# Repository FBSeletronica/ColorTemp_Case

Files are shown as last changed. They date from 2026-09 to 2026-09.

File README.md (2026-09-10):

# ColorTemp Case

3D-printed case for the [ColorTemp](https://github.com/MechatronixLab/ColorTemp/tree/master) project — a color-coded thermometer by Mechatronix Lab.

Modeled in OpenSCAD from the board's measurements (STEP), with a translucent lid that acts as a diffuser for the LED.

## Files

| File | Description |
|---|---|
| [ColorTemp_Case.scad](ColorTemp_Case.scad) | Parametric source (OpenSCAD) |
| [ColorTemp_Case_base.stl](ColorTemp_Case_base.stl) | Base, ready to slice |
| [ColorTemp_Case_lid.stl](ColorTemp_Case_lid.stl) | Lid/diffuser, ready to slice |

## Board fit

Base measurements (taken from the STEP file): 27.5 x 27.5 mm board, 1.6 mm thick.

- **USB-C** on the Y+ edge (connector rises 3.85 mm above the board)
- **Buttons** (SW1/SW2) on the X+ edge, with the actuator almost touching the wall
- The board snaps onto 4 locating pins and rests on standoffs
- A center hole in the bottom of the base allows for ventilation and lets you push the board out when disassembling

## Assembly

1. Snap the board onto the base's 4 locating pins.
2. Close the case by pressing the lid down until it locks onto the 4 snap blocks (1 per side) — no glue or screws needed.
3. To disassemble, push the board out from underneath through the base's center hole.

If the lid fit is too tight or too loose for your printer, adjust `snap_protrude`, `snap_depth`, or `fit_gap` near the top of the `.scad` file.

## Printing recommendations

- **0% infill** on both parts — with walls this thin, any infill would kill the lid's light diffusion and might even prevent it from closing properly.
- **Lid:** force **1 single perimeter/wall-loop** in your slicer (the default is usually 2+) to get a wall thin enough (~0.45–0.5 mm) to diffuse the LED's light. Tested with a 0.4 mm nozzle.
- **Neither part needs supports** — the lid's internal snap ramp is designed at ~45° and the snap blocks are just reliefs on a vertical wall.

## Generating the parts

At the end of `ColorTemp_Case.scad`, change the `part` variable to choose what to preview/export:

```scad
part = "base";        // base only
part = "lid";         // lid only
part = "both_apart";  // both parts side by side, already in the correct print orientation — use this to export/slice
part = "assembled";   // both parts stacked, just to VISUALLY CHECK the fit — not meant for printing
```

## Credits

- Electronics project: [ColorTemp — Mechatronix Lab](https://github.com/MechatronixLab/ColorTemp/tree/master)
- Case: Fabio / Embarcados

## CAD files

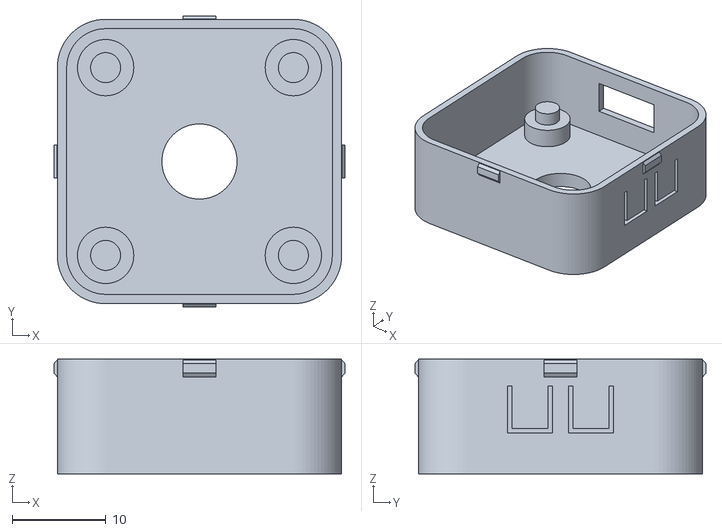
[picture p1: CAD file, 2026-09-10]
ColorTemp_Case_base.stl
31.0 x 31.0 x 12.2

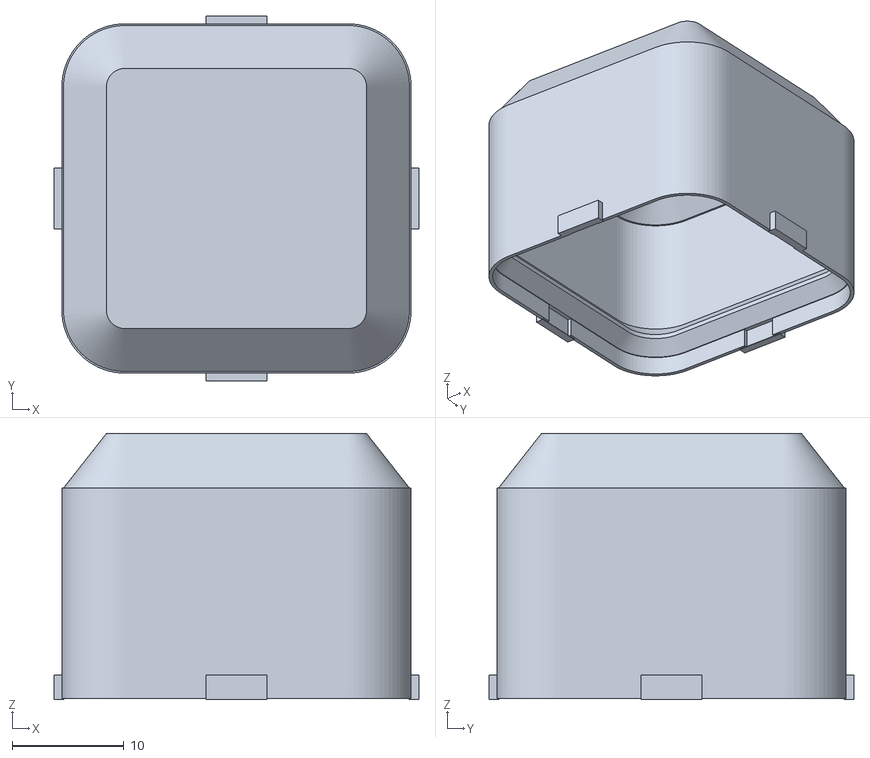
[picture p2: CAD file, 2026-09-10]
ColorTemp_Case_lid.stl
32.7 x 32.7 x 23.8

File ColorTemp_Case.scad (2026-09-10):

// ============================================================
//  Case para o projeto ColorTemp — A color coded thermometer
//  Projeto ColorTemp Mechatronix Lab
//  Link: https://github.com/MechatronixLab/ColorTemp/tree/master
//  Case By Fabio / Embarcados
// ============================================================
//
// COMO GERAR AS PECAS — mude a variavel `part` (fim do arquivo, bloco
// "SELEÇÃO DE PARTE") pra escolher o que ver/exportar:
//   "base"        -> so a base
//   "lid"         -> so a tampa
//   "both_apart"  -> as duas pecas lado a lado, cada uma ja na
//                    orientacao de impressao certa (a tampa vem
//                    rotacionada 180° — cupula pra baixo, encaixe pra
//                    cima) — e' essa a opcao pra exportar/fatiar
//   "assembled"   -> as duas empilhadas, uma sobre a outra, so pra
//                    CONFERIR VISUALMENTE o encaixe montado — nao
//                    serve pra imprimir (nao fatiar nesse modo)
//
// RECOMENDACOES DE IMPRESSAO:
//   - 0% de preenchimento nas duas peças no fatiador — com parede tão
//     fina, qualquer infill por dentro anula a difusão da tampa e
//     pode nem fechar direito.
//   - Tampa: force 1 unico perimetro/wall-loop no fatiador (o padrão
//     costuma ser 2+) — isso que faz a parede ficar fina o bastante
//     pra difundir a luz do LED. Testado com bico de 0.4mm
//     (~0.45-0.5mm de linha real); ver wall_t_lid mais abaixo.
//   - Nenhuma das duas peças precisa de suporte — a rampa interna do
//     encaixe da tampa (lid()) foi desenhada a ~45° especificamente
//     pra dispensar suporte; os blocos da trava (snap_*) sao so
//     relevos numa parede vertical, tambem sem suporte.
//   - Montagem: a placa entra na base encaixando nos 4 pinos
//     localizadores (boss_xy/pin_d/pin_h) antes de fechar a tampa; a
//     tampa trava por pressão nos 4 blocos da trava (snap_*, 1 por
//     face) — não precisa de cola nem parafuso, e dá pra abrir de
//     novo se precisar mexer na placa. Se o encaixe da tampa ficar
//     apertado/frouxo demais pro seu printer, ajustar snap_protrude/
//     snap_depth/fit_gap (comentados no bloco de parametros da trava).
//     Pra desmontar, da pra empurrar a placa pra fora dos pinos por
//     baixo, enfiando algo fino no furo central do fundo da base
//     (vent_hole_d) — o mesmo furo tambem deixa ar circular por baixo
//     da placa.
//
// MEDIDAS BASE (do STEP): placa 27.5x27.5mm, esp. 1.6mm; USB-C
// borda Y+ (sobe 3.85mm); botões borda X+ (atuador quase encosta
// na parede).
//
// TRAVA DA TAMPA: 4 blocos rigidos (1 por face, centralizado), direto
// na parede da base, travando no rebaixo correspondente da tampa —
// ver bloco de parametros e modulos snap_* mais abaixo.
// ============================================================

$fn = 72;

// ---------- PLACA (medido no STEP) ----------
board_size = 27.5;
board_t    = 1.6;

usbc_x_span   = [-4.62, 4.62];
usbc_h_above  = 3.85;
usbc_h_below  = 0.4;

btn_y        = [3.25, -3.25];   // SW1, SW2
btn_hole_h   = 2.6;
btn_z_bottom = -0.3;

// ---------- FOLGAS E FIXAÇÃO DA PLACA ----------
board_clear = 0.4;
floor_t     = 2.0;
standoff_h  = 2.5;
pin_d       = 3.2;
pin_h       = 1.7;
standoff_d  = 6.0;

// furo centralizado no fundo da base (atravessa o floor_t inteiro) —
// deixa entrar ar por baixo da placa e da pra empurrar a placa pra
// fora pelos pinos enfiando algo fino por ele. Centralizado em (0,0),
// bem longe dos 4 pinos/bosses (a ~14.1mm do centro, raio 3mm cada) —
// confira se nao ha nada sensivel embaixo da placa nessa area antes
// de imprimir, o script nao sabe o que tem na face de baixo dela.
vent_hole_d = 8.0;

// margem solida acima do recorte mais alto — dentro dela a tampa
// desliza livre ate um RESSALTO interno (ver lid()) que trava a
// profundidade, sempre no mesmo lugar
rim_margin = 2.3;   // minimo seguro: overlap_h (2.0) + 0.3mm de folga
overlap_h  = 2.0;      // profundidade de encaixe ate travar no ressalto
shoulder_w = 1.5;      // quanto o anel estreita acima do encaixe —
                        // e' nisso que a borda da base bate

// ---------- TRAVA DA TAMPA (bloco rigido, 1 por face, centralizado) ----------
// v6 — sem lingueta: o bloco fica direto na parede solida da base,
// sem corte em U ao redor (peca mais simples de imprimir/inspecionar).
// Segue sendo um BLOCO retangular (nao mais a esfera da v4, que
// afunilava ate virar um ponto e saia fraca/em fiapo na impressao) —
// secao constante do começo ao fim, com massa suficiente mesmo sem
// lingueta.
//
// Consequencia de tirar a lingueta: quem flexiona pra deixar o bloco
// passar volta a ser a parede FINA da tampa (na faixa de entrada ela
// e' so ~0.35mm de verdade — a cavidade ali e' dimensionada por
// fit_gap, nao por wall_t_lid). Por isso snap_protrude voltou a um
// valor conservador (mesmo raciocinio da v4 rigida).
//
// Centralizado em todas as 4 faces — o bloco fica bem acima do
// recorte mais alto (dentro do rim_margin), entao nao chega perto de
// botao nem USB-C mesmo centralizado.
snap_on       = true;   // liga/desliga a trava, pra comparar facil
snap_depth    = 1.0;    // profundidade do bloco, embutida na parede —
                         // LIMITE: a borda interna
                         // (case_w/2+snap_protrude-snap_depth) tem que
                         // ficar >= pocket_w/2 (~14.15mm) com folga,
                         // senao o bloco invade o bolso e trava a
                         // montagem da placa. Com os valores atuais
                         // sobra ~0.35mm — nao aumente sem recalcular.
snap_protrude = 0.35;   // quanto o bloco sai alem da face nominal —
                         // conservador de proposito (ver nota acima
                         // sobre a parede fina da tampa flexionar)
snap_clear    = 0.15;   // folga da cavidade da tampa em relacao ao bloco
snap_h        = 1.8;    // altura do bloco (Z)
snap_z_off    = 1.0;    // centro do bloco, medido do topo da base
                         // (func_h) pra baixo
snap_len      = 3.5;    // largura do bloco ao longo da face
snap_pad_t    = 0.7;    // reforco na parede FINA da tampa, so na
                         // regiao do rebaixo — sem isso o rebaixo
                         // fura essa parede por fora

// 1 bloco por face, centralizado
snap_normals = [ [1,0], [-1,0], [0,1], [0,-1] ];

// ---------- PEGADA / PROPORÇÃO DO CUBO ----------
// (case_r e' derivado mais abaixo, de pocket_r + wall_t_base, pra
// garantir que a tampa e a base tenham o MESMO raio de canto)

top_round_h = 5.0;
top_round_shrink = 4.0;
total_h     = 34.0;

// ---------- PAREDES (mais finas que a v4) ----------
wall_t_lid  = 0.5;    // parede da tampa (difusor) — alvo: 1 SO
                        // perimetro/wall-loop no fatiador (nao 2!),
                        // ~0.45-0.5mm com bico 0.4mm. 0% infill.
                        // Esse e' praticamente o minimo confiavel —
                        // abaixo disso a extrusora comeca a falhar
                        // linha (buracos, fios soltos).
wall_t_base = 1.0;    // parede da base — tambem mais fina, ainda
                        // deixa vazar um pouco de luz, aproximando o
                        // brilho do LED (que fica escondido aqui embaixo)
fit_gap     = 0.10;   // folga do encaixe (livre ate travar no ressalto) —
                       // era 0.15, reduzida porque o encaixe ainda
                       // ficava um pouco frouxo na pratica. De brinde,
                       // a parede da tampa na faixa de entrada
                       // (wall_t_lid - fit_gap) fica um pouco mais
                       // grossa tambem (0.35 -> 0.40mm). Se ainda
                       // ficar frouxo, dá pra descer mais — se ficar
                       // apertado demais pra montar, sobe de novo.

case_w = board_size + 2*(board_clear + wall_t_base);  // ~30.3mm

// ============================================================
// GEOMETRIA AUXILIAR
// ============================================================
module rrect(w, r) {
    hull() {
        for (sx = [-1, 1], sy = [-1, 1])
            translate([sx*(w/2 - r), sy*(w/2 - r)])
                circle(r = r);
    }
}

pocket_r = 3.75 + board_clear;
pocket_w = board_size + 2*board_clear;
boss_xy  = [ [10, 10], [-10, 10], [10, -10], [-10, -10] ];

// raio de canto EXTERNO, usado tanto pela base quanto pela tampa —
// derivado do raio real do bolso (que segue o formato da placa),
// nao mais um numero solto. Garante que base e tampa tenham o
// MESMO raio de canto, entao a folga (fit_gap) fica uniforme em
// toda a volta, inclusive nos 4 cantos — nao so nas faces retas.
case_r = pocket_r + wall_t_base;   // ~5.15mm

module pocket_cut(h, preserve_h) {
    difference() {
        linear_extrude(height = h)
            rrect(pocket_w, pocket_r);
        for (p = boss_xy)
            translate([p[0], p[1], -1])
                cylinder(h = preserve_h + 1, d = standoff_d);
    }
}
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

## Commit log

2026-09-09 Add initial design for ColorTemp case with detailed geometry and button cutouts
    [ColorTemp_Case.scad]
2026-09-09 Refine case dimensions and button flap design for improved fit and functionality
    [ColorTemp_Case.scad]
2026-09-09 Update pin dimensions for improved compatibility and fit
    [ColorTemp_Case.scad]
2026-09-09 Enhance ColorTemp case design with detailed assembly instructions and improved snap features for better fit and functionality
    [ColorTemp_Case.scad]
2026-09-10 Refine ColorTemp case design with improved snap features, ventilation hole, and adjusted fit dimensions for enhanced functionality
    [ColorTemp_Case.scad]
2026-09-10 Add initial STL files for ColorTemp case and lid designs
    [ColorTemp_Case_base.stl, ColorTemp_Case_lid.stl]
2026-09-10 Add README.md for ColorTemp case with assembly instructions and printing recommendations
